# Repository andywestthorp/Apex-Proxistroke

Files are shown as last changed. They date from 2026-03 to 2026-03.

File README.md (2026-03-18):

# Proxi-Type

### **Overview**

The **Proxi-Type** is a hardware-based credential injector designed as an assistive technology solution. Following a wrist injury that made repetitive typing painful, this device was created to automate the login process for various workstations. By tapping an authorised RFID tag, the device emulates a USB keyboard and securely types credentials.

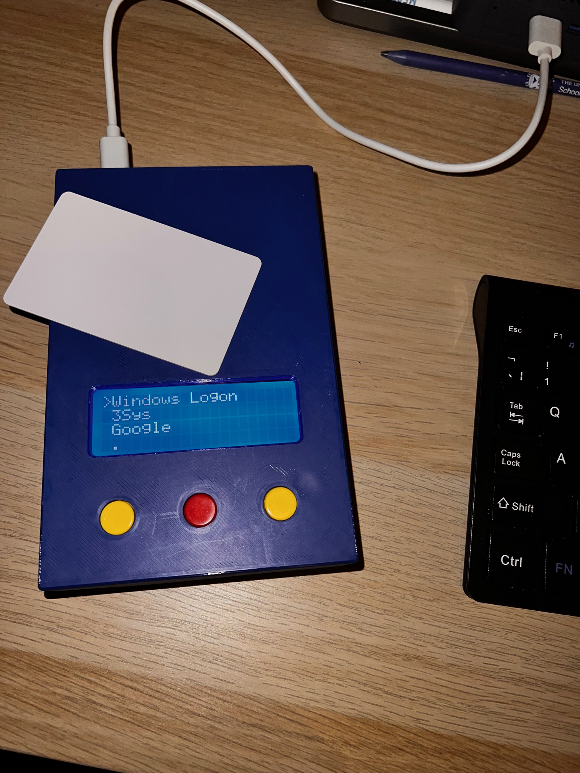
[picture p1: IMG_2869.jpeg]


### **Key Features**

* **Assistive HID Injection:** Emulates a standard USB keyboard; no drivers or software required on the host PC.
* **Secure Authentication:** Supports 1 Master Key and 2 User Key slots.
* **Interactive Serial Config:** Manage 5 unique credential slots (Service Name, Username, Password) via an interactive Serial wizard.
* **UK Keyboard Localisation:** Custom logic to handle British keyboard layouts, correctly rendering symbols like `@`, `"`, and `#`.
* **Emergency Hardware Reset:** A physical "cheat-code" bypass to wipe the system if the Master Key is lost.

---

## 🚀 Quick Start Guide

### **1. Hardware Setup**

Connect the device via USB. The LCD will display the **Proxi-Type** splash screen and load your menu. Use the **UP** and **DOWN** buttons to navigate and **SELECT** to choose an entry.

### **2. The "First Run" (Setting the Master Key)**

1. Scroll to `*** Configure ***` and press **SELECT**.
2. If no Master Key is set, the system grants **Emergency Access**.
3. Open the **Arduino Serial Monitor** (Baud: 9600, Newline).
4. Type `AUTH 0` and tap your intended Master Card on the reader.
5. Type `WRITE` to save permanently.

### **3. Editing Credentials**

While in the Serial Config menu:

1. Type `EDIT`.
2. Follow the prompts to enter the **Slot Number (0-4)**, **Service Name**, **Username**, and **Password**.
3. Type `WRITE` to save changes to the EEPROM.

---

## 🆘 Emergency Procedures

### **Hardware Reset (Manual Wipe)**

If you are locked out or the EEPROM contains corrupt data:

1. **Unplug** the device.
2. **Hold** both the **UP** and **DOWN** buttons.
3. **Plug in** the device while continuing to hold the buttons.
4. When `HARDWARE RESET` appears, press the **SELECT** button **3 times**.
5. The system will wipe all keys and credentials, returning you to the default state.

---

## 🛠️ Parts List

| Item | Qty | Component Description | Purpose |
| --- | --- | --- | --- |
| **Microcontroller** | 1 | Arduino Leonardo (or Pro Micro) | Logic & Native USB HID support. |
| **RFID Reader** | 1 | RC522 RFID Module (13.56MHz) | Authenticates users via tags. |
| **LCD Display** | 1 | 2004 LCD (20x4 Characters) | System UI. |
| **I2C Interface** | 1 | PCF8574 I2C Backpack | Reduces LCD wiring to 2 pins. |
| **Input** | 3 | Momentary Push Buttons | Navigation (Up, Down, Select). |
| **Authorisation** | 3+ | Mifare Classic 1K Tags | Master and User keys. |

---

## 🔌 Wiring Map

| Component | Pin (Leonardo) | Pin (Component) |
| --- | --- | --- |
| **LCD (I2C)** | 2 (SDA) / 3 (SCL) | SDA / SCL |
| **RFID (SPI)** | 10 | SDA (SS) |
| **RFID (SPI)** | 14 (MISO) / 16 (MOSI) | MISO / MOSI |
| **RFID (SPI)** | 15 (SCK) | SCK |
| **RFID (Power)** | 3.3V | 3.3V (**IMPORTANT**) |
| **Buttons** | 7, 8, 6 | Up, Down, Select |

---

### **Technical Tips for the Build**

* **Pro Micro vs Leonardo:** If you use a **Pro Micro**, the SPI pins (MISO/MOSI/SCK) are physically on pins 14, 16, and 15. On the full-sized **Leonardo**, they are often *only* accessible via the 6-pin ICSP header in the middle of the board.
* **Current Draw:** The RFID reader and the LCD backlight together can pull a decent amount of current. If the LCD looks dim or the RFID fails to read, double-check that your USB cable is high quality.
* **I2C Address:** If the screen lights up but shows no text, ensure the I2C address in the code (`0x27`) matches your hardware. You might also need to turn the small blue potentiometer on the back of the LCD to adjust the contrast.
* **RFID Voltage:** When assembling the Proxi-Type, pay close attention to the RFID module power. The RC522 is strictly a 3.3V device. Connecting it to the 5V rail will likely burn out the chip.
* **OnShape enclosure:**  Feel free to copy the enclosure here and 3d print your own.
If you make a less boring design, please share.

https://cad.onshape.com/documents/0ef05c768de59ed3a16de24d/w/20c9785c92aee0c8e3add6a8/e/77e8d892766bfce11dbebde7

⚖️ License

Distributed under the GNU v3 License.

    Permission is hereby granted, free of charge, to any person obtaining a copy of this software and associated documentation files...

Please feel free to modify, fork, or improve upon this design! I'm not sure about the name and the case is very dull, but it does the job. 

Andy. 15 March 2026

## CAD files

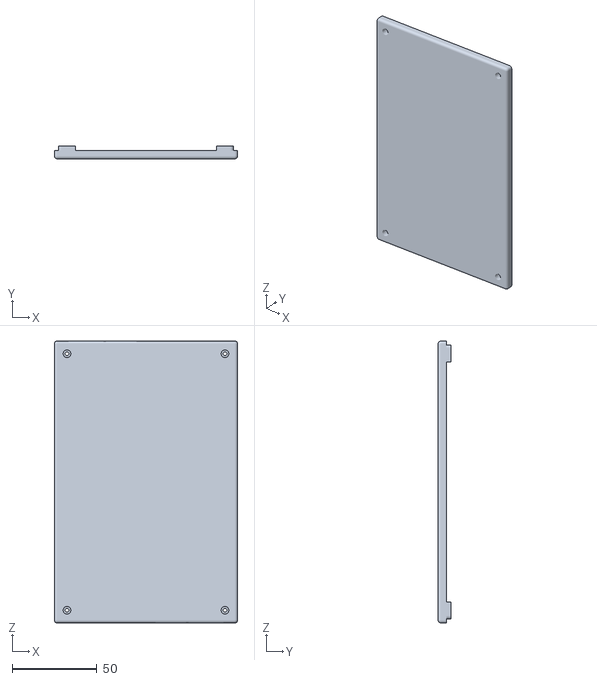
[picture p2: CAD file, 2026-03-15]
ProxType - Base.stl
108.0 x 7.50 x 166.0

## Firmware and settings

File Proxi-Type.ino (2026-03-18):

#include <SPI.h>
#include <MFRC522.h>
#include <LiquidCrystal_I2C.h> 
#include <Keyboard.h>
#include <EEPROM.h>

// --- I2C LCD DEFINITIONS ---
#define LCD_ADDR 0x27
#define LCD_COLS 20
#define LCD_ROWS 4
LiquidCrystal_I2C lcd(LCD_ADDR, LCD_COLS, LCD_ROWS);

// --- VERSION INFO ---
#define SYSTEM_NAME "Proxi-Type"
#define VERSION_DATE "v1.6.5 - 18/03/2026"

// --- PIN DEFINITIONS ---
#define BUTTON_UP    7 
#define BUTTON_DOWN  8 
#define BUTTON_SELECT 6
#define SS_PIN 10
#define RST_PIN 9

MFRC522 mfrc522(SS_PIN, RST_PIN);

// --- STORAGE ---
const int MAX_DATA_LENGTH = 64;
const int APP_COUNT = 5;
const int CONFIG_INDEX = APP_COUNT;
const int TOTAL_MENU_COUNT = APP_COUNT + 1;
const int AUTH_SLOTS = 3;

byte authorisedUIDs[AUTH_SLOTS][4]; 
char apps[APP_COUNT + 1][MAX_DATA_LENGTH];
char usernames[APP_COUNT + 1][MAX_DATA_LENGTH]; 
char passwords[APP_COUNT + 1][MAX_DATA_LENGTH];
int loginMode[APP_COUNT]; 

int currentAppIndex = 0; 
int menuLevel = 0; 
unsigned long lastMove = 0;

// --- UTILITIES ---

void typeUK(char* text) {
  for (int i = 0; i < (int)strlen(text); i++) {
    char c = text[i];
    if (c == '@') Keyboard.write('"');      
    else if (c == '"') Keyboard.write('@'); 
    else if (c == '#') Keyboard.write((char)0x32); 
    else Keyboard.write(c);
  }
}

void saveDataToEEPROM() {
    int addr = 0;
    for (int i = 0; i < APP_COUNT; i++) {
        EEPROM.put(addr, apps[i]);      addr += MAX_DATA_LENGTH;
        EEPROM.put(addr, usernames[i]); addr += MAX_DATA_LENGTH;
        EEPROM.put(addr, passwords[i]); addr += MAX_DATA_LENGTH;
        EEPROM.put(addr, loginMode[i]); addr += sizeof(int);
    }
    addr += 10; 
    for(int s = 0; s < AUTH_SLOTS; s++) {
        for(int b = 0; b < 4; b++) { EEPROM.write(addr++, authorisedUIDs[s][b]); }
    }
}

void loadDataFromEEPROM() {
    int addr = 0;
    for (int i = 0; i < APP_COUNT; i++) {
        EEPROM.get(addr, apps[i]);      addr += MAX_DATA_LENGTH;
        EEPROM.get(addr, usernames[i]); addr += MAX_DATA_LENGTH;
        EEPROM.get(addr, passwords[i]); addr += MAX_DATA_LENGTH;
        EEPROM.get(addr, loginMode[i]); addr += sizeof(int);
    }
    addr += 10;
    for(int s = 0; s < AUTH_SLOTS; s++) {
        for(int b = 0; b < 4; b++) { authorisedUIDs[s][b] = EEPROM.read(addr++); }
    }
    if (apps[0][0] == 0 || (byte)apps[0][0] == 255) {
        strcpy(apps[0], "Windows Unlock"); strcpy(usernames[0], "N/A"); strcpy(passwords[0], "pass");
        loginMode[0] = 2; 
    }
    strcpy_P(apps[CONFIG_INDEX], PSTR("*** Configure ***"));
}

void wipeSystem() {
    for(int s=0; s<AUTH_SLOTS; s++) for(int b=0; b<4; b++) authorisedUIDs[s][b] = 0;
    for(int i=0; i<APP_COUNT; i++) {
        strcpy(apps[i], "Empty Slot"); strcpy(usernames[i], "user"); 
        strcpy(passwords[i], "pass"); loginMode[i] = 0;
    }
    saveDataToEEPROM();
}

void showSplash() {
    lcd.clear();
    lcd.setCursor(5, 1);
    lcd.print(F("PROXI-TYPE"));
    lcd.setCursor(4, 2);
    lcd.print(VERSION_DATE);
    delay(2000); // Give 2 seconds to read the splash
}

void showHelp() {
    Serial.println(F("\n--- PROXI-TYPE HELP ---"));
    Serial.println(F("DUMP        - Show credentials."));
    Serial.println(F("EDIT        - Modify a slot."));
    Serial.println(F("AUTH [0-2]  - Set RFID cards."));
    Serial.println(F("WRITE       - Save to EEPROM."));
    Serial.println(F("RESET       - Factory wipe."));
    Serial.println(F("EXIT        - Back to menu."));
    Serial.println(F("HELP        - Show this list."));
    Serial.println(F("\nMODES: 0=Std, 1=Delay, 2=PwdOnly"));
    Serial.println(F("-----------------------"));
}

// --- UI & AUTH ---

void updateMenu() {
    lcd.clear();
    int startItem = (currentAppIndex >= LCD_ROWS) ? currentAppIndex - (LCD_ROWS - 1) : 0;
    for (int i = 0; i < LCD_ROWS; i++) {
        int itemIdx = startItem + i;
        if (itemIdx < TOTAL_MENU_COUNT) {
            lcd.setCursor(0, i);
            lcd.print(itemIdx == currentAppIndex ? F(">") : F(" ")); 
            lcd.print(apps[itemIdx]);
        }
    }
}

bool isAuthorised() {
    lcd.clear();
    lcd.setCursor(4, 0); lcd.print(F("PROXI-TYPE"));
    lcd.setCursor(2, 1); lcd.print(F("TAP MASTER/USER"));
    unsigned long startWait = millis();
    while (millis() - startWait < 10000) {
        if (mfrc522.PICC_IsNewCardPresent() && mfrc522.PICC_ReadCardSerial()) {
            int matchedSlot = -1;
            for (int s = 0; s < AUTH_SLOTS; s++) {
                bool match = true;
                for (byte i = 0; i < 4; i++) { if (mfrc522.uid.uidByte[i] != authorisedUIDs[s][i]) match = false; }
                if (match) { matchedSlot = s; break; }
            }
            mfrc522.PICC_HaltA();
            if (matchedSlot != -1) {
                lcd.setCursor(2, 2); lcd.print(F("ACCESS GRANTED"));
                delay(1000); return true;
            } else {
                lcd.setCursor(4, 2); lcd.print(F("INVALID KEY!")); delay(1000); return false;
            }
        }
        if (digitalRead(BUTTON_SELECT) == LOW) return false;
        delay(50);
    }
    return false;
}

// --- CONFIG ---

void serialEdit() {
    Serial.println(F("\nSlot (0-4):"));
    while (!Serial.available());
    int slot = Serial.parseInt();
    while (Serial.available()) Serial.read(); 

    if (slot >= 0 && slot < APP_COUNT) {
        Serial.println(F("App Name:"));
        while (!Serial.available()); String sName = Serial.readStringUntil('\n'); sName.trim();
        sName.toCharArray(apps[slot], MAX_DATA_LENGTH);

        Serial.println(F("User:"));
        while (!Serial.available()); String uName = Serial.readStringUntil('\n'); uName.trim();
        uName.toCharArray(usernames[slot], MAX_DATA_LENGTH);

        Serial.println(F("Pass:"));
        while (!Serial.available()); String pWord = Serial.readStringUntil('\n'); pWord.trim();
        pWord.toCharArray(passwords[slot], MAX_DATA_LENGTH);

        Serial.println(F("Mode (0=Std, 1=Delay, 2=PwdOnly):"));
        while (!Serial.available());
        loginMode[slot] = Serial.parseInt();
        while (Serial.available()) Serial.read();

        Serial.println(F("Staged. Type WRITE to save."));
    }
}

void configureMode() {
    if (Serial.available()) {
        String command = Serial.readStringUntil('\n'); command.trim(); command.toUpperCase();
        if (command == "DUMP") {
            Serial.println(F("\n--- STORED DATA ---"));
            for (int i = 0; i < APP_COUNT; i++) {
                Serial.print(i); Serial.print(F(": ")); Serial.print(apps[i]);
                Serial.print(F(" | Mode: ")); Serial.print(loginMode[i]);
                Serial.print(F(" | U: ")); Serial.print(usernames[i]);
                Serial.print(F(" | P: ")); Serial.println(passwords[i]);
            }
        } 
        else if (command == "HELP") { showHelp(); }
        else if (command == "EDIT") { serialEdit(); }
        else if (command.startsWith("AUTH")) {
            int slot = command.substring(5).toInt();
            Serial.println(F("TAP CARD..."));
            unsigned long sA = millis();
            while(millis() - sA < 10000) {
                if (mfrc522.PICC_IsNewCardPresent() && mfrc522.PICC_ReadCardSerial()) {
                    for(int i=0; i<4; i++) authorisedUIDs[slot][i] = mfrc522.uid.uidByte[i];
                    Serial.println(F("RECORDED.")); break;
                }
            }
        }
        else if (command == "WRITE") { saveDataToEEPROM(); Serial.println(F("SAVED.")); }
        else if (command == "RESET") { wipeSystem(); Serial.println(F("WIPED.")); }
        else if (command == "EXIT") { menuLevel = 0; updateMenu(); }
    }
}

void checkHardwareReset() {
    if (digitalRead(BUTTON_UP) == LOW && digitalRead(BUTTON_DOWN) == LOW) {
        unsigned long holdStart = millis();
        lcd.clear(); lcd.setCursor(3, 1); lcd.print(F("HOLD FOR RESET"));
        while (digitalRead(BUTTON_UP) == LOW && digitalRead(BUTTON_DOWN) == LOW) {
            int progress = (millis() - holdStart) / 30; 
            lcd.setCursor(0, 2);
            for(int i=0; i<20; i++) {
                if (i < progress/5) lcd.print(F(">")); else lcd.print(F(" "));
            }
            if (millis() - holdStart > 3000) {
                lcd.clear(); lcd.print(F("CONFIRM: SELECT x3"));
                int c = 0;
                while (c < 3) {
                    if (digitalRead(BUTTON_SELECT) == LOW) {
                        c++; lcd.setCursor(8, 2); lcd.print(c); lcd.print(F("/3"));
                        while(digitalRead(BUTTON_SELECT) == LOW); delay(200);
                    }
                }
                wipeSystem();
                lcd.clear(); lcd.print(F("SYSTEM WIPED"));
                delay(2000);
                return;
            }
            delay(10);
        }
    }
}

void setup() {
    Serial.begin(9600);
    lcd.init(); lcd.backlight();
    pinMode(BUTTON_UP, INPUT_PULLUP);
    pinMode(BUTTON_DOWN, INPUT_PULLUP);
    pinMode(BUTTON_SELECT, INPUT_PULLUP);

    // 1. Check for Reset (High Priority)
    checkHardwareReset();
    
    // 2. Show the Splash screen
    showSplash();

    // 3. Init hardware and load data
    SPI.begin(); mfrc522.PCD_Init();
    Keyboard.begin();
    loadDataFromEEPROM();
    
    // 4. Draw the first menu
    updateMenu();
}

void loop() {
    if (menuLevel == 0) {
        if (digitalRead(BUTTON_UP) == LOW && (millis() - lastMove > 200)) {
            currentAppIndex = (currentAppIndex <= 0) ? TOTAL_MENU_COUNT - 1 : currentAppIndex - 1;
            updateMenu(); lastMove = millis();
        }
        if (digitalRead(BUTTON_DOWN) == LOW && (millis() - lastMove > 200)) {
            currentAppIndex = (currentAppIndex >= TOTAL_MENU_COUNT - 1) ? 0 : currentAppIndex + 1;
            updateMenu(); lastMove = millis();
        }
    }

    if (digitalRead(BUTTON_SELECT) == LOW && (millis() - lastMove > 500)) {
        lastMove = millis();
        while(digitalRead(BUTTON_SELECT) == LOW);

        if (menuLevel == 2) { 
            menuLevel = 0; updateMenu();
        } 
        else if (currentAppIndex == CONFIG_INDEX) { 
            bool masterKeySet = false;
            for(int i=0; i<4; i++) { if(authorisedUIDs[0][i] != 0) masterKeySet = true; }
            if (!masterKeySet || isAuthorised()) { 
                menuLevel = 2; 
                lcd.clear(); lcd.setCursor(3, 1); lcd.print(F("SERIAL CONFIG"));
                showHelp();
            } else { updateMenu(); }
        } 
        else {
            if (isAuthorised()) {
                lcd.clear(); lcd.print(F("PROXI-TYPING..."));
                if (loginMode[currentAppIndex] != 2) {
                  typeUK(usernames[currentAppIndex]);
                  if (loginMode[currentAppIndex] == 1) {
                    Keyboard.write(KEY_RETURN); 
                    delay(1200); 
                  } else {
                    Keyboard.write(KEY_TAB); 
                  }
                }
                typeUK(passwords[currentAppIndex]); 
                Keyboard.write(KEY_RETURN);
                delay(2000); 
            }
            updateMenu();
        }
    }

    if (menuLevel == 2) configureMode();
    delay(10);
}

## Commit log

2026-03-15 Update version to v1.5.3
    Additional features include a hardware reset on boot - in case the EEPROM gets corrupted.
2026-03-15 Revise README for clarity and structure
    Updated the README to improve clarity and organization, including a new overview, key features, and detailed setup instructions. Also a link to OnShape for the case.
2026-03-15 Added STL files for the enclosure
    Here are some easy 3d printable files, should you wish to make a boring box.
    [ProxType - Base.stl]
